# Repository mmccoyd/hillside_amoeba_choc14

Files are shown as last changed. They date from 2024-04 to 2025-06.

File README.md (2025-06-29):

# Hillside Amoeba Choc14

| | |
|:--- |:---|
| Panel front | Amoeba Use |

These are single-switch PCBs for Choc spaced Dactyl keyboards.

They allow Choc 18 mm or narrower column spacing,
  sturdier column walls, and Mill-Max hot swap.
Each has a PCBA SOD-123 diode, holes for a Choc v1 switch with optional
    Mill-Max sockets, and wire solder holes for creating the switch matrix.
The diode is from column anode+ to row cathode-.

Goals include
  allowing most of the matrix soldering to be done outside of the case
  and allowing reuse of the switches and matrix in a future case.

See the [wiki](https://github.com/mmccoyd/hillside_amoeba_choc14/wiki)
    for ordering details and wiring suggestions.
Their use is illustrated in the
    [Hillside Dactyl 50](https://github.com/mmccoyd/hillside_dactyl_50)
    wiki.

## Size and fit

The PCBs are 13.7 wide x 16 mm deep.

That is only as wide as the bottom of a choc switch,
  but adds a small top and bottom lip
  to prevent removal of the switch from pulling the PCB out of the key well.
Side notches serve to keep the top to bottom position aligned
  with the keyboard-body's switch-socket hole and to
  prevent the PCB from falling into the switch hole.

## Panel layout

The fabrication panel spacing matches that seen in a typical Dactyl key well.
That simplifies building by allowing much of the wiring to be done
  before splitting the PCBs out of the panel.

The column separation in the panel
  has a bit of slack for the intervening key well wall.
This mirrors what is likely needed in the key well 
  for the usually parallel pinkie and index columns.
The panel separation of 20 mm adds 2 mm to the choc 18 mm column separation.

The row edge-to-edge separation
    leaves a decent tab between the PCBs
    to grip with pliers to break the PCBs cleanly apart.
The separation of 6 mm adds 2 mm to the key well 3.8 mm separation
  for a column of 16 mm PCBs with a 15 degree curve.

## Version status

-   Alpha.4: Net yet tested. Has the larger SOD-123 diodes for hand soldering.
-   Alpha.3: Used without PCBA by A SadWitch. Has the small SOD-323 diodes.
-   Alpha.2: I used with PCBA for my Hillside Dactyl 50 alpha.2 and alpha.3.

## Images

Images of use in a build are in the
    [Hillside Dactyl 50](https://github.com/mmccoyd/hillside_dactyl_50) wiki.

Use back
Panel front
Panel back
Schematic

## Other Choc Amoeba options

There are a few other choc Amoebas, though they have wider footprints:

- [Amoeba-choc](https://github.com/girishji/amoeba-choc)
  with monochrome LED and lower power draw, plus Kailh hotswap.
- [Nydas Amoeba](https://github.com/nydasco/nydas_keyboard_v2/tree/main/NydasAmoeba)
  with SK6812-mini-e LED and Kailh hotswap.
- [MxLEDBit](https://keycapsss.com/keyboard-parts/pcbs/173/mxledbit-single-switch-pcb-mx-choc-hot-swap-socket)
  with SK6812-mini-e LED and no hotswap.
- [Skree](https://www.skree.us) has MX spaced amoebas that also take choc switches.
- [su120](https://github.com/kissetfall/su120-keyboard/tree/master)

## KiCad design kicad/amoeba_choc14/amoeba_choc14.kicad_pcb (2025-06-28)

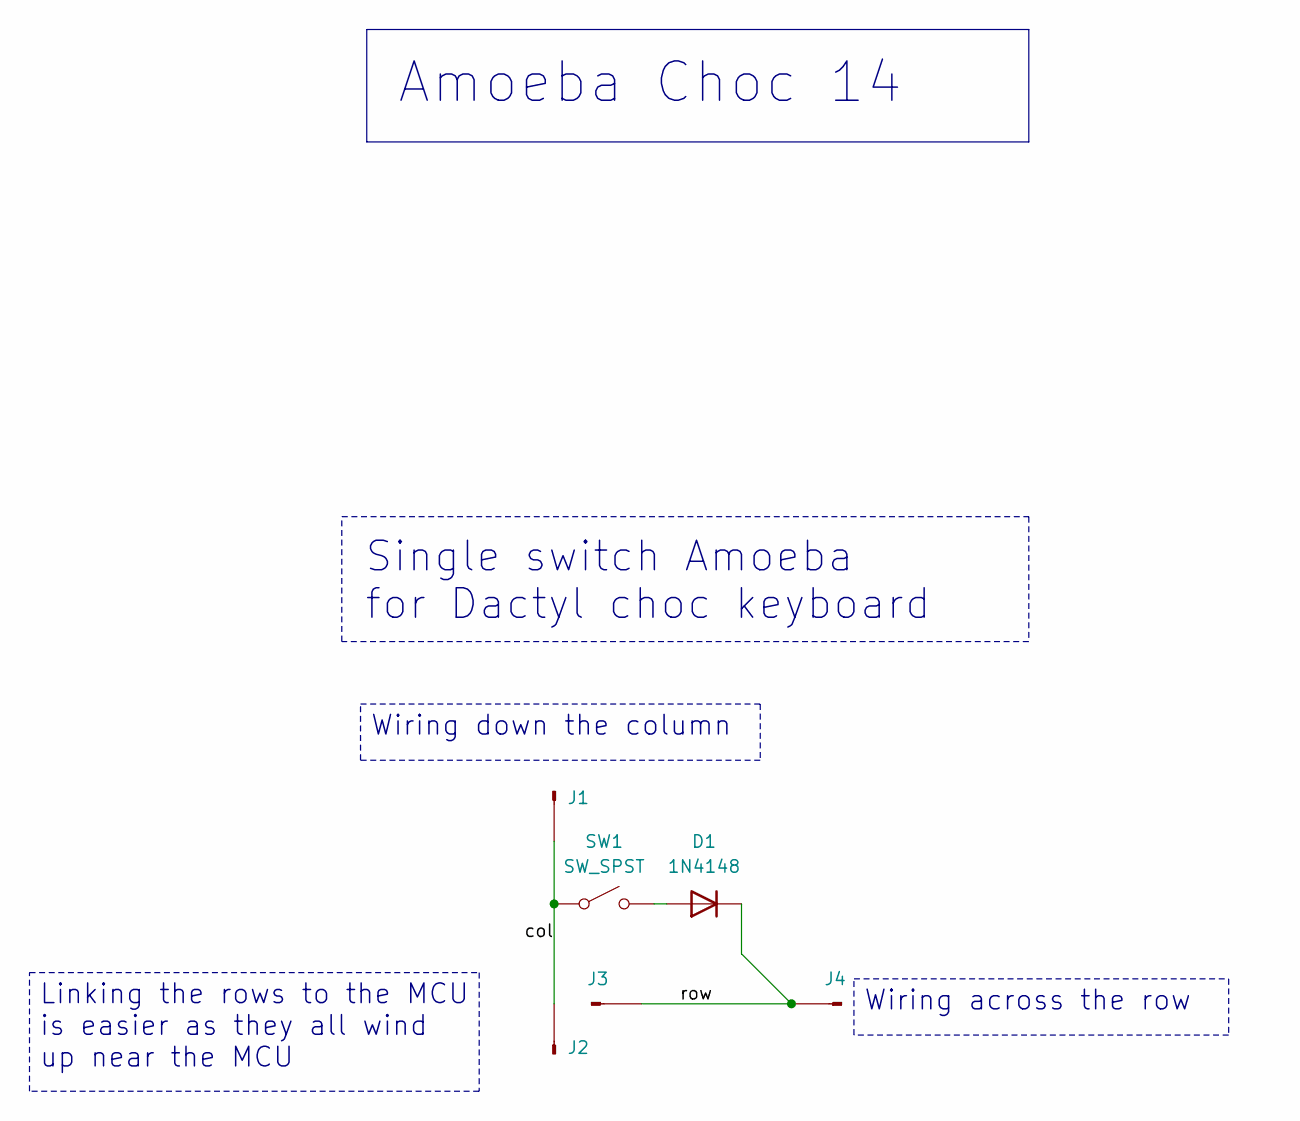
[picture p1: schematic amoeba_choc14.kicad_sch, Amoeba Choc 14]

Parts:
D1: 1N4148; D_SOD-123; LCSC C81598
J1, J2, J3, J4: Conn_01x01_Pin; Pin_D0.8mm_L7.0mm
SW1: SW_SPST; pg1350-hotswap

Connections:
/col: J1.1, J2.1, SW1.1 (A)
/row: D1.1 (K), J3.1, J4.1
unnamed: D1.2 (A), SW1.2 (B)

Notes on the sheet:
${TITLE}
Linking the rows to the MCU is easier as they all wind up near the MCU
Single switch Amoeba for Dactyl choc keyboard
Wiring down the column
Wiring across the row

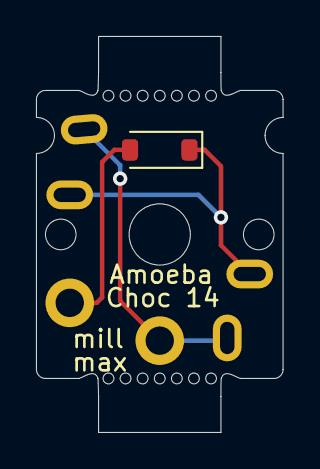
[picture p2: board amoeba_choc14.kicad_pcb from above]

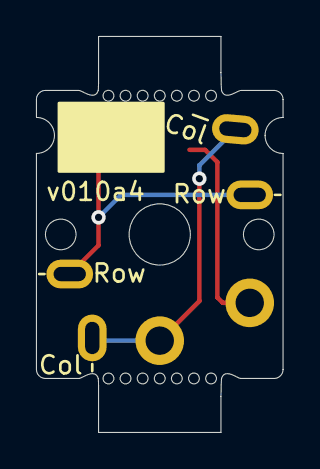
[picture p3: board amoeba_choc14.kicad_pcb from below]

Board: 2 copper layers, 13.7 x 22.0 mm, 6 parts (4 on the bottom side), 3 nets.

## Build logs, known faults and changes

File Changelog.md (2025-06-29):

# Change Log

## 0.1.0-alpha.4

Not yet tested. But the changes are simple and here for those who will be hand
soldering.

-   SOD-123 diodes for easier hand soldering.
-   Silk
    -   Fewer silk wire tick marks as they add clutter when doing
        post-solder cleanup.
    -   Logo on panel lower rail.
    -   Fix panel typo on choc column width.

## 0.1.0-alpha.3

This version has wording and layout improvements, tooling hole and
fiducial mark moves, and an update to KiCad 9.

This isn't an essential update. The previous version, 0.1.0-alpha.2
works just as well.

I haven't fabricated this version yet.
But the changes are simple and I created a JLC order without issue.

Changes

-   Panel
    -   Tooling holes and fiducial marks moved to side rails.
    -   Re-insert Amoeba after its version bump.
-   Panel silk
    -   More notes on use.
    -   Auxiliary information moved to the side panels.
-   Amoebas
    -   Bump version to limit confusion and straighten a trace.
-   KiCad update to version 9.

Alpha.3 is the last version using the smaller SOD-323 diodes.

## 0.1.0-alpha.2

-   Amoeba 
    -   Matching holes offset for easier wire slack.
    -   Oval soldering holes.
-   Panel
    -   Tidy up tooling holes and fiducial marks. Use three not four.
    -   Silk
        -   Typical wiring layout around the back outer frame.
        -   More room for long order numbers.
-   Used in building Hillside Dactyl 50 0.1.0-alpha.2 and alpha.3.

## 0.1.0-alpha.1

-   Works fine, but some tweaks would be good.
-   Used in building Hillside Dactyl 50 0.1.0-alpha.1.

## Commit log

2024-04-11 feat: empty KiCad project
    [AmoebaChocNarrow.kicad_pcb, AmoebaChocNarrow.kicad_sch]
2024-04-11 feat: project sheet description; KiCad defaults
    [AmoebaChocNarrow.kicad_pcb, AmoebaChocNarrow.kicad_sch]
2024-04-11 feat: create footprint library
2024-04-11 feat: choc, diode, connectors, silk. rename folder
    [AmoebaChocNarrow.kicad_pcb, AmoebaChocNarrow.kicad_sch]
2024-04-11 feat(foot): 1 pin connector
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2024-04-11 feat(foot): mouse bites just hole no larger mask
2024-04-11 feat(foot): switch: show hole and choc space size
2024-04-11 feat(amoeba): clean up, hold just amoeba area
    [AmoebaChocNarrow.kicad_pcb]
2024-04-11 feat(panel): 4x5 panel, mouse bites, silk versions
    [AmoebaPanel.kicad_pcb]
2024-04-11 feat(foot): diode on front
2024-04-11 feat(amoeba): cleanup
    [AmoebaChocNarrow.kicad_pcb, AmoebaChocNarrow.kicad_sch]
2024-04-11 refactor: rename folders to amoeba/ and panel/
    [AmoebaChocNarrow.kicad_pcb, AmoebaChocNarrow.kicad_sch, AmoebaPanel.kicad_pcb]
2024-04-11 feat(PCBA): rough copy of KiBot from hillside
2024-04-11 refactor: rename v2
    [AmoebaChocNarrow.kicad_pcb, AmoebaChocNarrow.kicad_sch]
2024-04-11 refactor: kicad precision cleanup
2024-04-11 refactor: rename v3
    [amoeba_choc14.kicad_pcb, amoeba_choc14.kicad_sch]
2024-04-11 fix: label vs mask, update dioode from lib
    [amoeba_choc14.kicad_pcb, amoeba_choc14.kicad_sch]
2024-04-11 feat(PCBA): add LCSC number for diode
    [amoeba_choc14.kicad_pcb, amoeba_choc14.kicad_sch]
2024-04-11 feat(debug): disable KiBot BOM
2024-04-11 feat(debug): PCBA SMD only
2024-04-11 feat(debug): PCBA simplify options
2024-04-11 feat(debug): PCBA not separate files
2024-04-11 feat(foot): extrude from BOM and position file
2024-04-11 feat: extrude from BOM and position file
    [amoeba_choc14.kicad_pcb, amoeba_choc14.kicad_sch]
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2024-04-11 feat: update PCB footprint
    [amoeba_choc14.kicad_pcb]
2024-04-11 feat(CI): BOM only smd
2024-04-11 feat: Config "do not fit"
    [amoeba_choc14.kicad_pcb, amoeba_choc14.kicad_sch]
2024-04-11 feat(CI): use default dnf filter
2024-04-11 feat(CI): use explicit dnf filter
2024-04-11 feat(CI): debug no BOM
2024-04-11 feat(CI): debug BOM ignore_dnf
2024-04-11 feat(schematic): exclude switch from BOM
    [amoeba_choc14.kicad_sch]
2024-04-11 feat(CI): debug exclude marked in pcb
2024-04-11 feat: POS exclude in pcb
    [amoeba_choc14.kicad_pcb]
2024-04-11 feat: project clearance update from kicad
2024-04-11 feat(amoeba): extra column pad for MCU connection
    [amoeba_choc14.kicad_pcb, amoeba_choc14.kicad_sch]
2024-04-11 feat(sch): Title block info
    [amoeba_choc14.kicad_sch]
2024-04-11 feat(panel): 5 x 5 grid, docs
    [AmoebaPanel.kicad_pcb]
2024-05-01 feat(foot): width 13.7 mm
2024-05-01 feat: width 13.7 mm, clearer row/col silk
    [amoeba_choc14.kicad_pcb, amoeba_choc14.kicad_sch]
2024-05-01 feat(panel): update for width 13.7mm
    [AmoebaPanel.kicad_pcb]
2024-05-01 doc: cleanup readme. Ordering, design, wiring.
2024-05-14 feat(foot): mouse bites for panel rails
2024-05-14 feat(panel): mouse bites on rails, fix lib path
    [AmoebaPanel.kicad_pcb]
2024-05-14 feat: longer bite tabs for breakoff; mini ver num
    [amoeba_choc14.kicad_pcb, amoeba_choc14.step]
2024-05-14 feat(panel): longer bite tabs for breakoff
    [AmoebaPanel.kicad_pcb]
2024-05-15 feat: use SOD-323 diode, as 123 out of stock
    [amoeba_choc14.kicad_pcb, amoeba_choc14.kicad_sch]
2024-05-15 feat(foot): fix tooling hole must be unplated
2024-05-15 feat(pcb): update for SOD-323
    [amoeba_choc14.kicad_pcb]
2024-05-15 feat(panel): update for SOD-323
    [AmoebaPanel.kicad_pcb]
2024-05-15 doc: note diode options if out of stock
2024-05-24 feat(panel): tidy up tooling holes and silk
    [AmoebaPanel.kicad_pcb]
2024-06-01 feat(foot): choc: use labels not box for mill max
2024-06-01 feat(foot): wire solder hole: oval shape
2024-06-01 feat: oval wire pads offset for easier curve
    [amoeba_choc14.kicad_pcb, amoeba_choc14.kicad_sch]
2024-06-01 feat(panel): label rows and thumbs on edge rails
    [AmoebaPanel.kicad_pcb]
2024-08-23 feat(pcb): use slots for wire holes. better bites
    - Row and col are slots to more easily cram wire into them.
    - No extra lower column pad
    - Better separation between upper col and row
    - Mouse bites recessed so broken edge should lie inside the board outline.
    [amoeba_choc14.kicad_pcb, amoeba_choc14.kicad_sch]
2024-08-23 feat(step): update export
    [amoeba_choc14.step]
2024-08-23 feat(panel): space out to match wiring distances
    [AmoebaPanel.kicad_pcb]
2024-08-23 feat(panel): panel shows a sample wiring layoout
    [AmoebaPanel.kicad_pcb]
2024-08-23 refactor: move kicad into own dir kicad/
2024-08-23 refactor: move kicad into own directory
    [AmoebaPanel.kicad_pcb, amoeba_choc14.kicad_pcb, amoeba_choc14.kicad_sch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]
2025-04-17 ci: remove ci as using KiCad JLC build plugin
2025-04-17 feat(KiCad): update to KiCad 9
2025-04-17 feat(panel): better wording, move tooling holes
    [AmoebaPanel.kicad_pcb]
2025-04-17 feat(amoeba): bump version, straighten trace
    - update to KiCad 9
    - increase font size in schematic
    [amoeba_choc14.kicad_pcb, amoeba_choc14.kicad_sch]
2025-04-17 feat(panel): re-insert Amoeba
    [AmoebaPanel.kicad_pcb]
2025-04-17 feat(panel): silk wording tweaks
    [AmoebaPanel.kicad_pcb]
2025-04-17 ci: release build kicad file churn..
    [AmoebaPanel.kicad_pcb]
2025-04-17 chore: update panel release date
    [AmoebaPanel.kicad_pcb]
2025-06-28 feat(amoeba): SOD-123 diode, fewer silk tick marks
    [amoeba_choc14.kicad_pcb, amoeba_choc14.kicad_sch]
2025-06-28 feat(panel): fix silk typo, add art, bump version
    [AmoebaPanel.kicad_pcb]
2025-06-28 feat(panel): updated amoeba
    [AmoebaPanel.kicad_pcb]
2025-06-28 feat(panel): exclude logo from parts lists
    [AmoebaPanel.kicad_pcb]
